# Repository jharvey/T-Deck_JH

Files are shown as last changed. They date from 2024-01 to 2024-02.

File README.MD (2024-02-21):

LilyGO T-Deck 18650 enclosure

This enclosure can sit in a window charging the batteries either via solar or USB. It charges battery 1 first, then when bat1 is full, it charges battery 2, and eventually battery 3. Any of the 3 batteries can power the TDeck. It can operate with no batteries as long as USB is providing power. The circuit board includes
- over and under voltage protection
- short circuit protection 
- multi stage charging
- battery temperature protection
- charging via solar or USB 

These files include the PCB layout and 3D files for an 18650 based T-Deck enclosure. 

3D source files can be found at onshape [Here](https://cad.onshape.com/documents/b289702058d3b69984c9ded4/w/4e1c5bb6efe28ab1e1699733/e/336c687f36e879030984626b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)

PCB files can be found at EasyEDA [Here](https://oshwlab.com/easyeda_jh/tdeck_18650_charger)

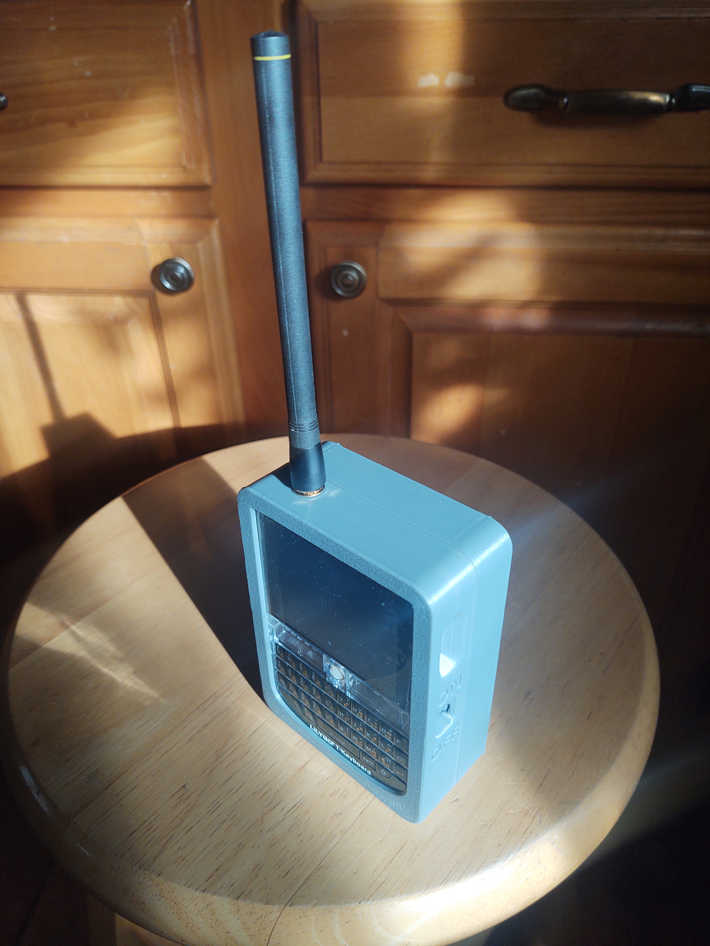
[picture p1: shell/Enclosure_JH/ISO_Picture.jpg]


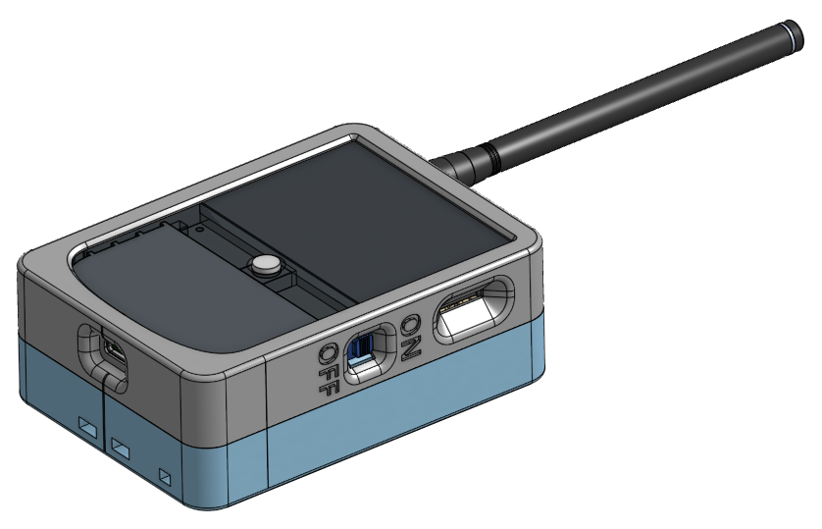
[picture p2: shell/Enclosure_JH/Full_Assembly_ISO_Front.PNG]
Top ISO


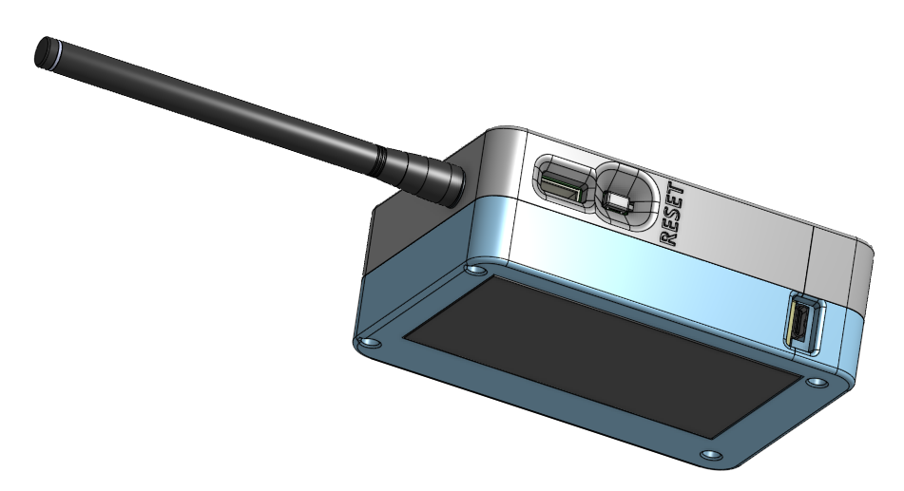
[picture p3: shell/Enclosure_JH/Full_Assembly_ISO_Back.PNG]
Bottom ISO


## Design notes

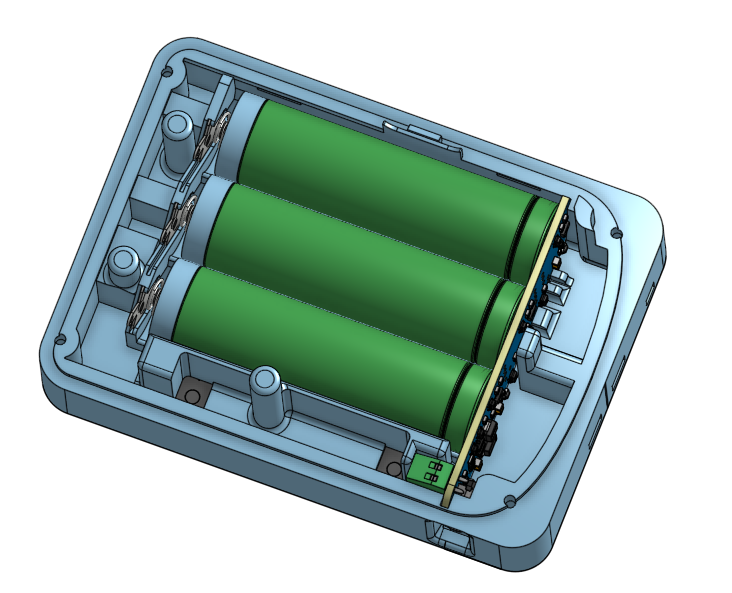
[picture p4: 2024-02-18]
shell/Enclosure_JH/T-Deck_Back_Shell_18650-Solar_OnShape/ISO_insides.PNG

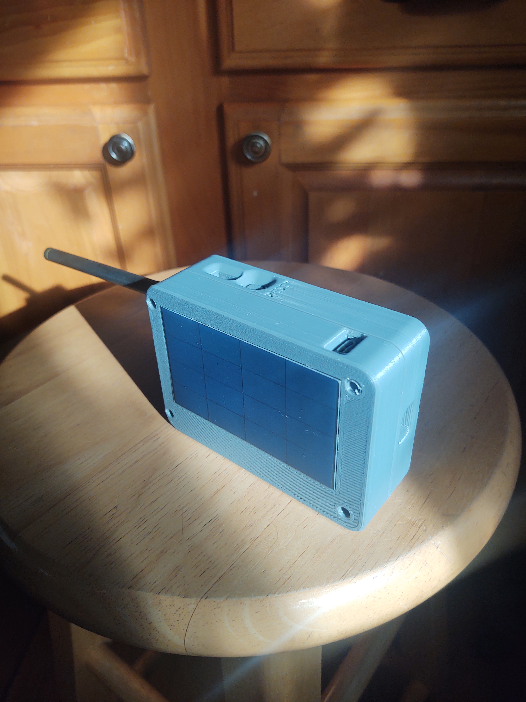
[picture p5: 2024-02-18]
shell/Enclosure_JH/Side_Picture.jpg

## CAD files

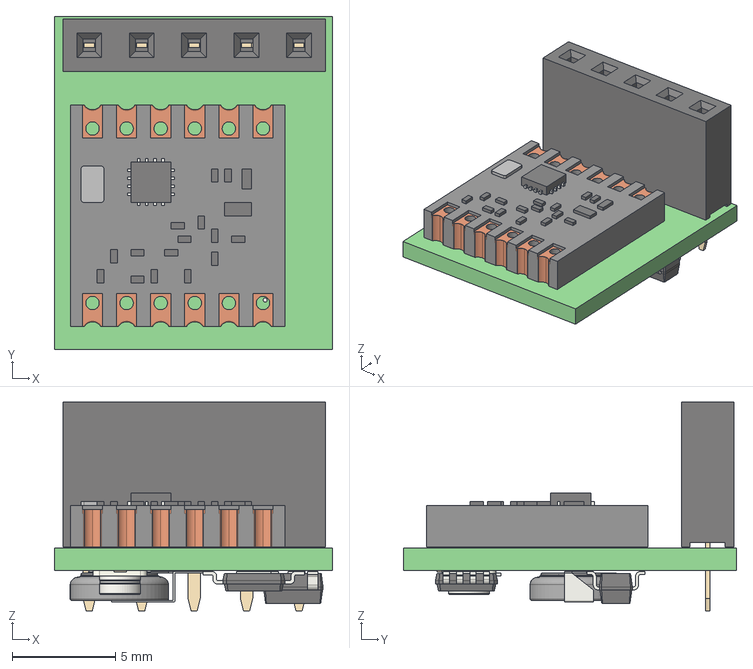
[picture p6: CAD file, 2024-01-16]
schematic/Misc/GPS_Module_Mockup_Kicad/GPS_Module.step
13.5 x 16.1 x 10.1 mm
GPS_Module PCB

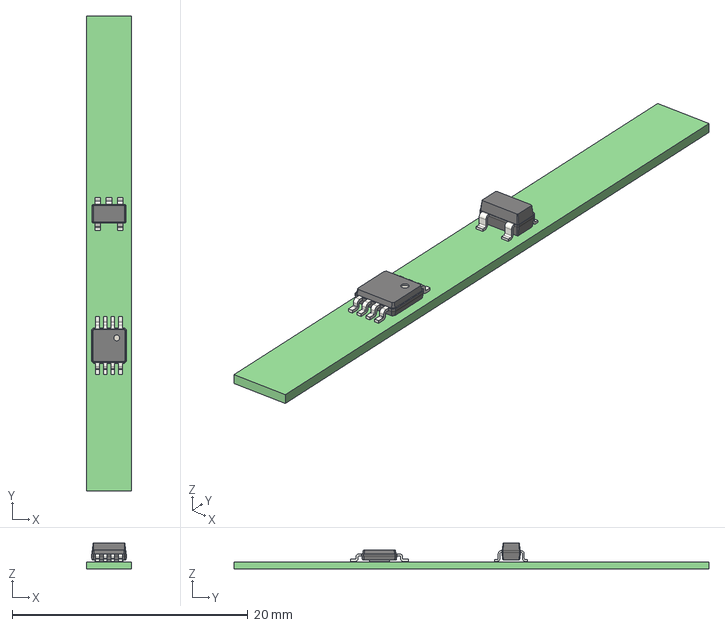
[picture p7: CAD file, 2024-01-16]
schematic/Misc/UVP_Short_Protection_Mockup_KiCad/UVP_Short_Protection.step
3.81 x 40.3 x 2.20 mm
UVP_Short_Protection PCB

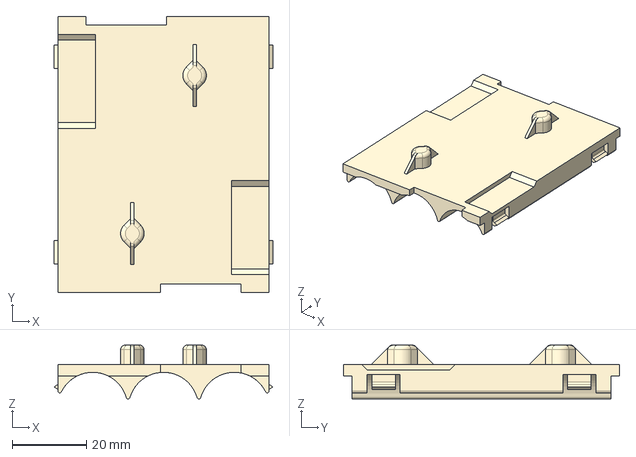
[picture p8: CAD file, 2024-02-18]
shell/Enclosure_JH/T-Deck_Back_Shell_18650-Solar_OnShape/R0.1/TD-Mid.step
58.9 x 74.3 x 14.5 mm

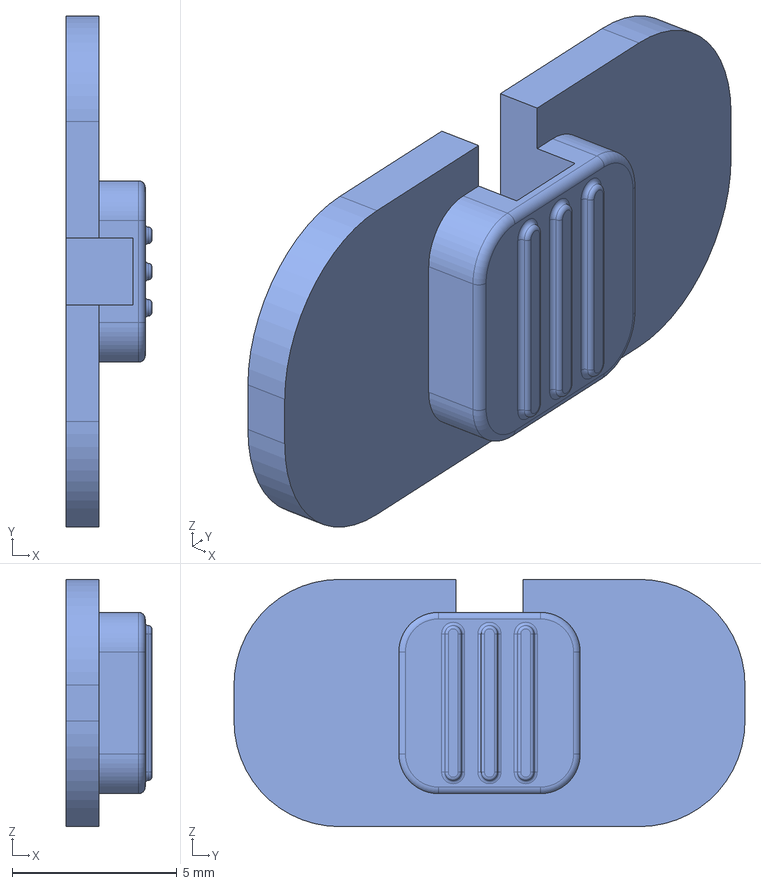
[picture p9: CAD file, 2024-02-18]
shell/Enclosure_JH/T-Deck_Front_Shell_OnShape/R0.1/T_Deck_PWR_Switch.step
2.60 x 15.5 x 7.50 mm

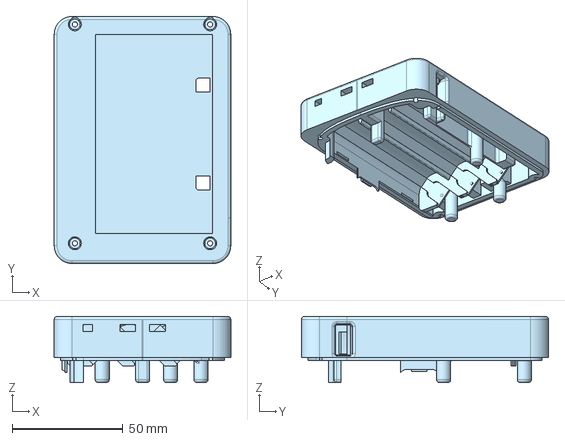
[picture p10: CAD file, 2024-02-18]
shell/Enclosure_JH/T-Deck_Back_Shell_18650-Solar_OnShape/R0.1/TD-Bot.step
79.8 x 111.6 x 29.9 mm

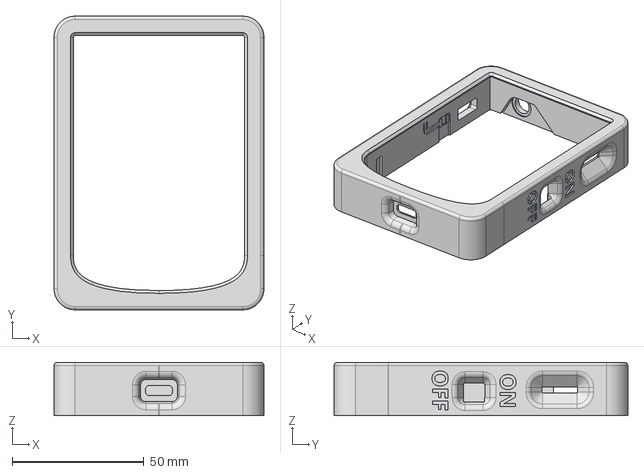
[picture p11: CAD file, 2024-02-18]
shell/Enclosure_JH/T-Deck_Front_Shell_OnShape/R0.1/TD-Top.step
79.8 x 111.6 x 20.3 mm

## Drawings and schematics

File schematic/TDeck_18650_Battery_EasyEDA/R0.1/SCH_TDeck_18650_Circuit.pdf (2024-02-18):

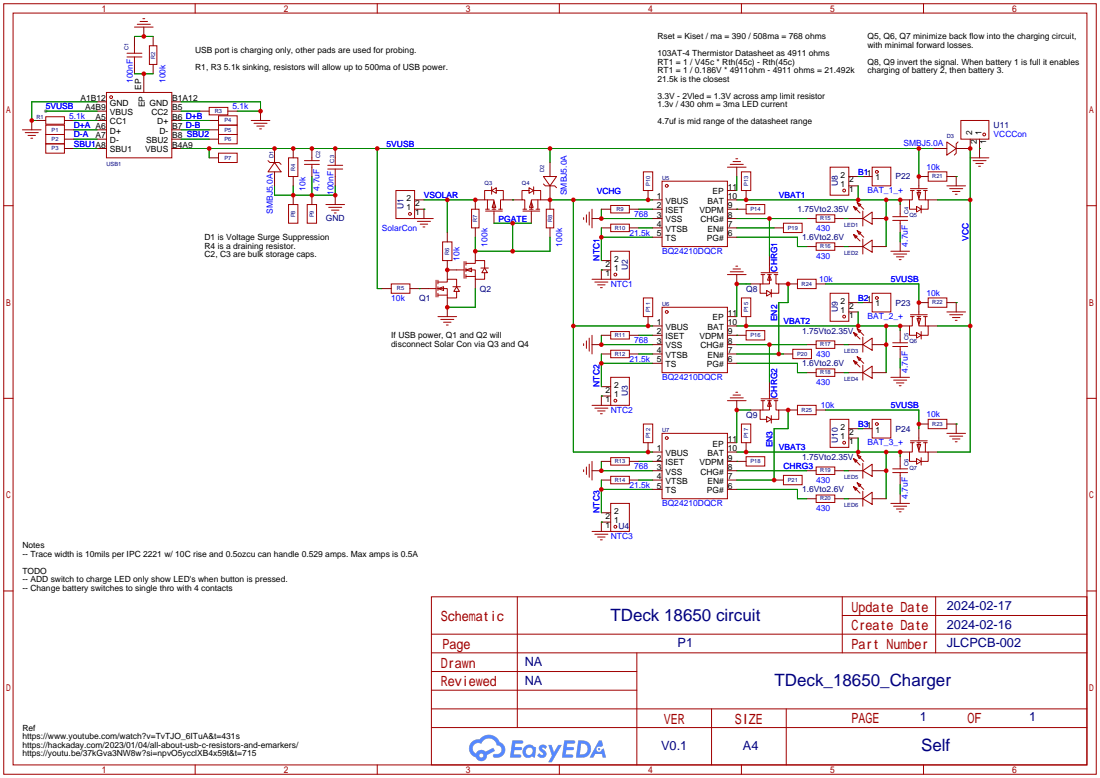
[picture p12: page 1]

Rset = Kiset / ma = 390 / 508ma = 768 ohms
103AT-4 Thermistor Datasheet as 4911 ohms
RT1 = 1 / V45c * Rth(45c) - Rth(45c)
RT1 = 1 / 0.186V * 4911ohm - 4911 ohms = 21.492k
21.5k is the closest
3.3V - 2Vled = 1.3V across amp limit resistor
1.3v / 430 ohm = 3ma LED current
4.7uf is mid range of the datasheet range

Q5, Q6, Q7 minimize back flow into the charging circuit,
with minimal forward losses.
Q8, Q9 invert the signal. When battery 1 is full it enables
charging of battery 2, then battery 3.

USB port is charging only, other pads are used for probing.
R1, R3 5.1k sinking, resistors will allow up to 500ma of USB power.

D1 is Voltage Surge Suppression
R4 is a draining resistor.
C2, C3 are bulk storage caps.

If USB power, Q1 and Q2 will
disconnect Solar Con via Q3 and Q4

Notes
-- Trace width is 10mils per IPC 2221 w/ 10C rise and 0.5ozcu can handle 0.529 amps. Max amps is 0.5A
TODO
-- ADD switch to charge LED only show LED's when button is pressed.
-- Change battery switches to single thro with 4 contacts

Ref
https://www.youtube.com/watch?v=TvTJO_6ITuA&t=431s
https://hackaday.com/2023/01/04/all-about-usb-c-resistors-and-emarkers/
https://youtu.be/37kGva3NW8w?si=npvO5ycclXB4x59t&t=715

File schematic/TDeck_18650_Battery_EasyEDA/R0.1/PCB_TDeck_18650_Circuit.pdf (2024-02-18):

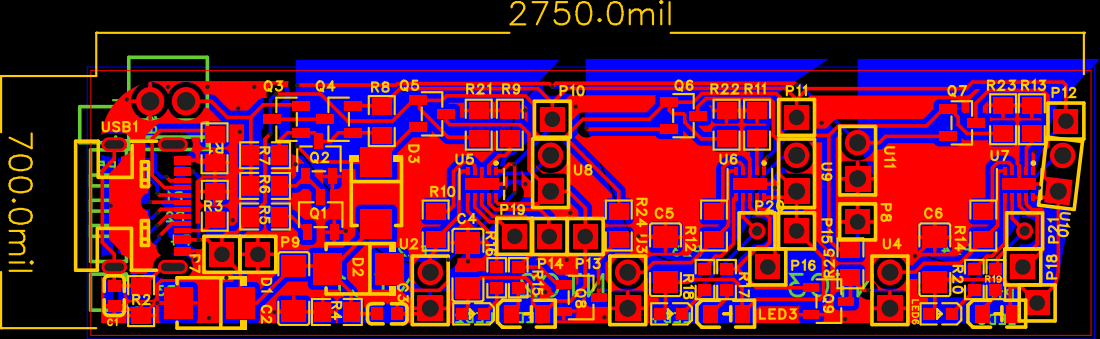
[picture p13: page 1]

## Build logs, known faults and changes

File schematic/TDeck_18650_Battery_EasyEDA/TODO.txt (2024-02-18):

-- Add silk screen to back side of PCB. Free bill board, use it for something.
--

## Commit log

2024-01-16 Draft / archive commit
    [GPS_Module.kicad_pcb, GPS_Module.kicad_sch, GPS_Module.step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]
2024-02-11 Draft Check in, PCB for enclosure
2024-02-18 Moving files around
    [GPS_Module.kicad_pcb, GPS_Module.kicad_sch, GPS_Module.step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]
2024-02-18 More Cleanup removing files I'm not changing.
    [T-Deck.dxf, T-Deck.stp, T_Deck_1.stp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]
2024-02-18 R0.1 Checked in
    [GPS_Module.kicad_pcb, GPS_Module.kicad_sch, GPS_Module.step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]
